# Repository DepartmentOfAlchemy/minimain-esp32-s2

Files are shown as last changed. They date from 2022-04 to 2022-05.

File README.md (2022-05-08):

## MiniMain ESP32-S2

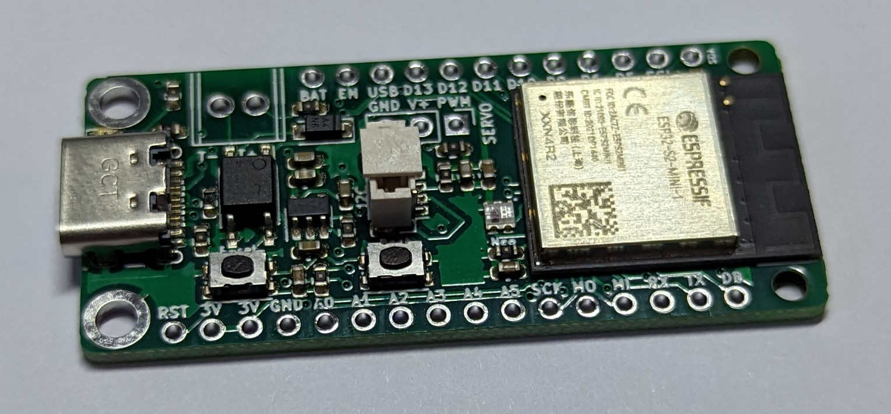
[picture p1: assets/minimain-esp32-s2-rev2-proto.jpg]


PCB files for the MiniMain ESP32-S2 in an Adafruit Feather compatible format.

### Description

This Feather-shaped main board contains an ESP32-S2 for the main microcontroller. It contains 4 MB of flash + 2 MB of PSRAM along with native USB.

This board is designed for use in haunted attraction props as it includes an optoisolated input that allows it to be triggered by another prop controller operating at 12V. This is where the MiniMain deviates from a standard Adafruit Feather: it does not include support for battery operation. (There is also one additional pin broken out in standard 2.54mm pitch format designed for a servo.)

### License

Inspired by [Adafruit Feather ESP32-S2](https://github.com/adafruit/Adafruit-Feather-ESP32-S2-PCB). Adafruit invests time and resources providing this open source design, please support Adafruit and open-source hardware by purchasing products from [Adafruit](https://www.adafruit.com)!

Adafruit Feather ESP32-S2 designed by Limor Fried/Ladyada for Adafruit Industries.

MiniMain ESP32-S2 designed by Jesse Peterson/cubeinhabitant.

Creative Commons Attribution/Share-Alike

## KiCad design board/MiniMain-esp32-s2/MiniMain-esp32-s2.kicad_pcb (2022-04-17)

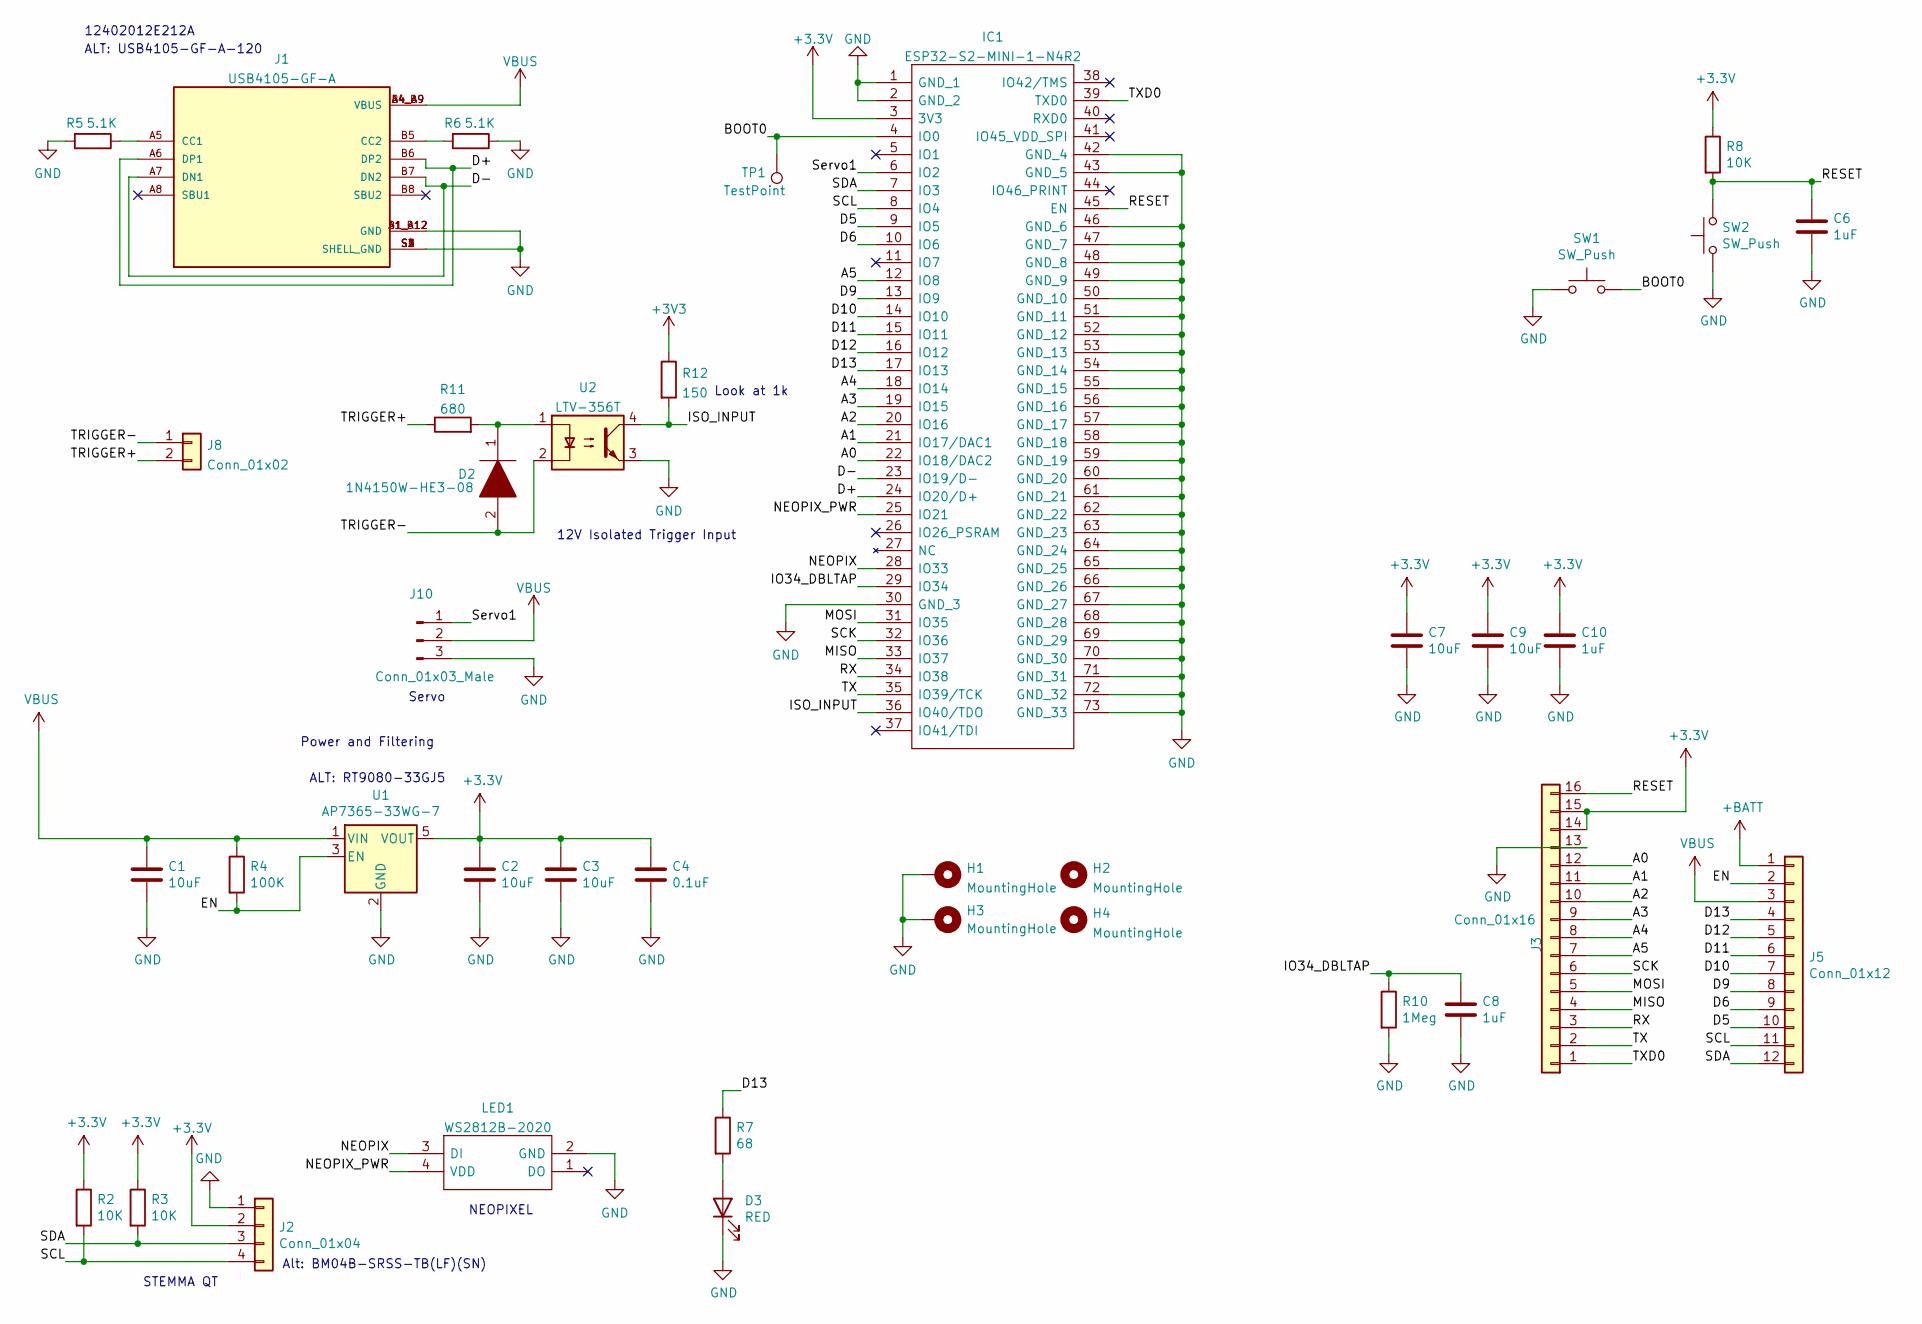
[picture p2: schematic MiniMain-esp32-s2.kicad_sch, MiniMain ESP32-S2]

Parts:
C1, C2, C3, C9: 10uF; C_0603_1608Metric
C4: 0.1uF; C_0603_1608Metric
C6, C8, C10: 1uF; C_0603_1608Metric
C7: 10uF; C_0402_1005Metric
D2: 1N4150W-HE3-08; D_SOD-123; Manufacturer_Part_Number S1GTR
D3: RED; LED_0603_1608Metric
H1, H3: MountingHole; MountingHole_2.7mm_M2.5_ISO14580_Pad
H2, H4: MountingHole; MountingHole_2.7mm_M2.5_ISO14580
IC1: ESP32-S2-MINI-1-N4R2; ESP32S2MINI1N4R2; Manufacturer_Part_Number ESP32-S2-MINI-1-N4R2; Mouser Part Number 356-ESP32S2MINI1N4R2
J1: USB4105-GF-A; GCT_USB4105-GF-A; PARTREV A3
J2: Conn_01x04; JST_SH_BM04B-SRSS-TB_1x04-1MP_P1.00mm_Vertical
J3: Conn_01x16; PinHeaderPlain_1x16_P2.54mm_Vertical
J5: Conn_01x12; PinHeaderPlain_1x12_P2.54mm_Vertical
J8: Conn_01x02; OSTVN02A150
J10: Conn_01x03_Male; PinHeader_1x03_P2.54mm_Vertical
LED1: WS2812B-2020; WS2812B2020; Manufacturer_Part_Number WS2812B-2020
R2, R3, R8: 10K; R_0603_1608Metric
R4: 100K; R_0603_1608Metric
R5, R6: 5.1K; R_0603_1608Metric
R7: 68; R_0603_1608Metric
R10: 1Meg; R_0603_1608Metric
R11: 680; R_0603_1608Metric
R12: 150; R_0603_1608Metric
SW1, SW2: SW_Push; SW_Push_1P1T_NO_CK_KMR2
TP1: TestPoint; TestPoint_Pad_D1.5mm
U1: AP7365-33WG-7; SOT-23-5
U2: LTV-356T; SO-4_4.4x3.6mm_P2.54mm

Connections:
+BATT: J5.1
/A0: IC1.22 (IO18/DAC2), J3.12
/A1: IC1.21 (IO17/DAC1), J3.11
/A2: IC1.20 (IO16), J3.10
/A3: IC1.19 (IO15), J3.9
/A4: IC1.18 (IO14), J3.8
/A5: IC1.12 (IO8), J3.7
/BOOT0: IC1.4 (IO0), SW1.2, TP1.1
/D5: IC1.9 (IO5), J5.10
/D6: IC1.10 (IO6), J5.9
/D9: IC1.13 (IO9), J5.8
/D10: IC1.14 (IO10), J5.7
/D11: IC1.15 (IO11), J5.6
/D12: IC1.16 (IO12), J5.5
/D13: IC1.17 (IO13), J5.4, R7.1
/D+: IC1.24 (IO20/D+), J1.A6 (DP1), J1.B6 (DP2)
/D-: IC1.23 (IO19/D-), J1.A7 (DN1), J1.B7 (DN2)
/EN: J5.2, R4.2, U1.3 (EN)
/IO34_DBLTAP: C8.1, IC1.29 (IO34), R10.1
/ISO_INPUT: IC1.36 (IO40/TDO), R12.2, U2.4
/MISO: IC1.33 (IO37), J3.4
/MOSI: IC1.31 (IO35), J3.5
/NEOPIX: IC1.28 (IO33), LED1.3 (DI)
/NEOPIX_PWR: IC1.25 (IO21), LED1.4 (VDD)
/RESET: C6.1, IC1.45 (EN), J3.16, R8.2, SW2.2
/RX: IC1.34 (IO38), J3.3
/SCK: IC1.32 (IO36), J3.6
/SCL: IC1.8 (IO4), J2.4, J5.11, R2.2
/SDA: IC1.7 (IO3), J2.3, J5.12, R3.2
/Servo1: IC1.6 (IO2), J10.1
/TRIGGER+: J8.2, R11.1
/TRIGGER-: D2.2, J8.1, U2.2
/TX: IC1.35 (IO39/TCK), J3.2
/TXD0: IC1.39 (TXD0), J3.1
GND: C1.2, C2.2, C3.2, C4.2, C6.2, C7.2, C8.2, C9.2, C10.2, D3.1 (K), H1.1, H3.1, IC1.1 (GND_1), IC1.2 (GND_2), IC1.30 (GND_3), IC1.42 (GND_4), IC1.43 (GND_5), IC1.46 (GND_6), IC1.47 (GND_7), IC1.48 (GND_8), IC1.49 (GND_9), IC1.50 (GND_10), IC1.51 (GND_11), IC1.52 (GND_12), IC1.53 (GND_13), IC1.54 (GND_14), IC1.55 (GND_15), IC1.56 (GND_16), IC1.57 (GND_17), IC1.58 (GND_18), IC1.59 (GND_19), IC1.60 (GND_20), IC1.61 (GND_21), IC1.62 (GND_22), IC1.63 (GND_23), IC1.64 (GND_24), IC1.65 (GND_25), IC1.66 (GND_26), IC1.67 (GND_27), IC1.68 (GND_28), IC1.69 (GND_29), IC1.70 (GND_30), IC1.71 (GND_31), IC1.72 (GND_32), IC1.73 (GND_33), J1.A1_B12 (GND), J1.B1_A12 (GND), J1.S1 (SHELL_GND), J1.S2 (SHELL_GND), J1.S3 (SHELL_GND), J1.S4 (SHELL_GND), J2.1, J3.13, J10.3, LED1.2 (GND), R5.2, R6.1, R10.2, SW1.1, SW2.1, U1.2 (GND), U2.3
unnamed: D2.1, R11.2, U2.1
unnamed: D3.2 (A), R7.2
unnamed: J1.A5 (CC1), R5.1
unnamed: J1.B5 (CC2), R6.2
VBUS: C1.1, J1.A4_B9 (VBUS), J1.B4_A9 (VBUS), J5.3, J10.2, R4.1, U1.1 (VIN)

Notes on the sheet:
Alt: BM04B-SRSS-TB(LF)(SN)
ALT: RT9080-33GJ5
NEOPIXEL
12402012E212A
12V Isolated Trigger Input
ALT: USB4105-GF-A-120
STEMMA QT
Look at 1k
Servo
Power and Filtering

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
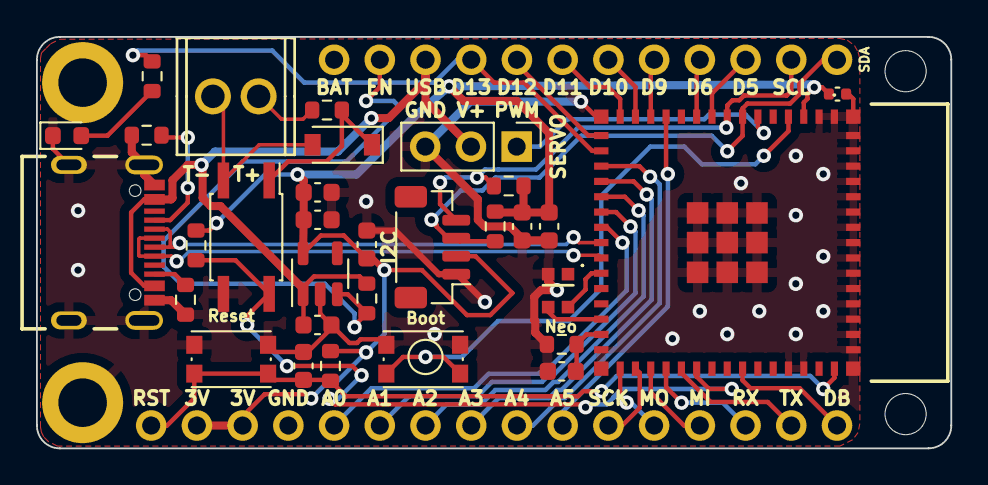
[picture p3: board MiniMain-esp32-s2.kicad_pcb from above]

Board: 2 copper layers, 50.8 x 22.9 mm, 38 parts (0 on the bottom side), 40 nets.

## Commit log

2021-12-30 Initial board commit.
    [MiniMain.kicad_pcb, MiniMain.sch]
2021-12-31 Added support for turning power off on the "Stemma QT" port like in the Adafruit esp32-s2 feather.
    [MiniMain.sch]
2022-02-13 Updated the gitignore with the KiCad specific values.
2022-02-13 Board layout complete with silkscreen done.
    [MiniMain.kicad_pcb, MiniMain.kicad_sch, MiniMain.sch]
2022-02-13 Fix a few unconnected nets. DRC now shows nothing unconnected.
    [MiniMain.kicad_pcb]
2022-02-23 Revealed the values of the components in the front fab so that I can see where each component goes for board population.
    [MiniMain.kicad_pcb]
2022-02-26 Minor update for the fabrication layer for part location.
    [MiniMain.kicad_pcb]
2022-04-03 Renamed to more accurately reflect that this is for an ESP32-S2. Also added the revision of 0.1.
    [MiniMain-esp32-s2.kicad_pcb, MiniMain-esp32-s2.kicad_sch, MiniMain-esp32-s2.sch]
2022-04-17 Rev 2: Change Stemma QT compatible port from transistor controlled power to just +3.3V. Remove copper pour under the ESP32-S2 antenna. Perhaps look at changing the isolated input pull-up from 150 ohm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
    [MiniMain-esp32-s2.kicad_pcb, MiniMain-esp32-s2.kicad_sch]
2022-04-17 Rev 2: PCB changes after DRC. (Even though I didn't change anything.)
    [MiniMain-esp32-s2.kicad_pcb]
2022-05-08 License added. Also added photo of Rev 2 prototype. (#1)
2022-05-08 Update README.md
    Fix a couple spelling issues.
